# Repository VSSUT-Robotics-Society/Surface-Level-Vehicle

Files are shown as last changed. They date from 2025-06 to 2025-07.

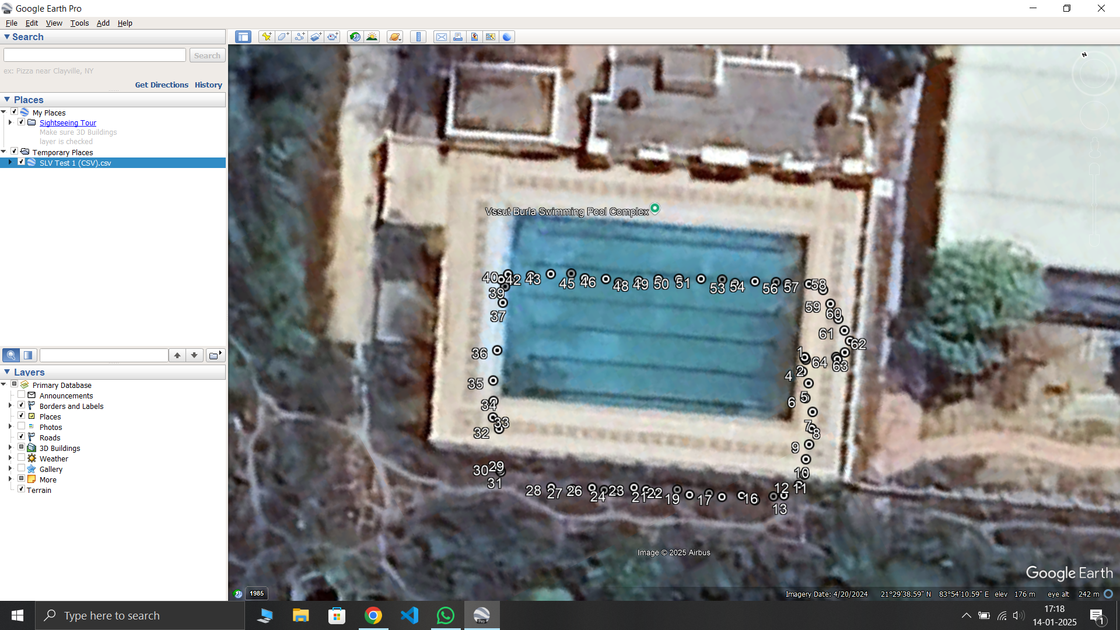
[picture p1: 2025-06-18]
Test Runs/Test_1 - Swimming Pool/SLV Test 1 (image).png

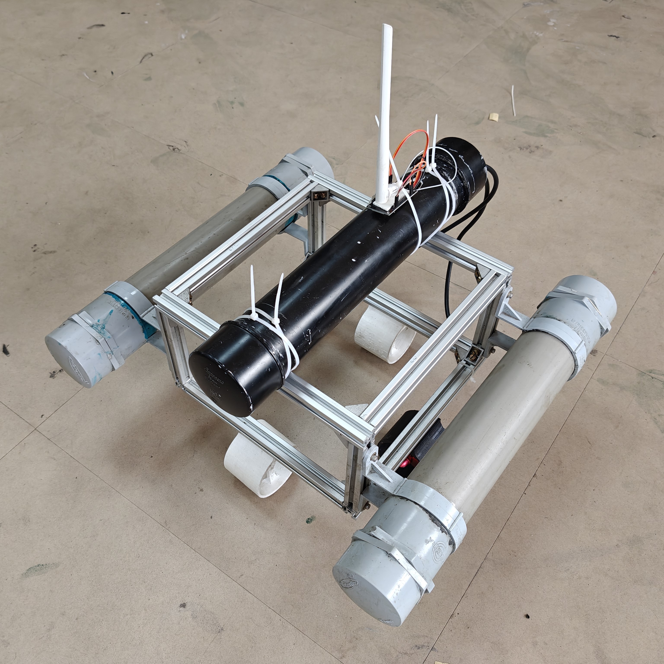
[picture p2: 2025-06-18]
Assets/1.jpg

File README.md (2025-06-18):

# Surface Level Vehicle (SLV)

An autonomous surface water robot designed for environmental monitoring, research, and rescue operations.

---

## Table of Contents
1. [Overview](#overview)
2. [Our Goals](#our-goals)
3. [What We Currently Use](#what-we-currently-use)
    - [Hardware](#hardware)
    - [Software](#software)
    - [Packages](#packages)
4. [How to Run the Project](#how-to-run-the-project)
    - [Installation](#installation)
5. [Problems Currently Being Faced](#problems-currently-being-faced)
6. [Bill of Materials Required](#bill-of-materials-required)
7. [Future Applications/Features](#future-applicationsfeatures)
8. [References](#references)

---

## Overview

The Surface Level Vehicle (SLV) is an unmanned watercraft designed for surface-level operations. It incorporates a lightweight, durable aluminum extrusion frame for structural support, enhancing stability, modularity, and ease of assembly. Powered by four BLDC motors and equipped with GPS for autonomous navigation, the SLV is built for efficient and precise aquatic missions.

---

## Our Goals

- Develop a cost-effective and modular surface vehicle.
- Enable autonomous water navigation using GPS.
- Support various environmental, research, and safety applications.
- Ensure stability, durability, and ease of customization.

---

## What We Currently Use

### Hardware

- Aluminum extrusion frame  
- 4 × High-RPM BLDC motors with waterproof propellers  
- 2 × Air-filled PVC pipes (floatation)  
- GPS module  
- Rechargeable battery pack  
- Waterproof enclosures

### Software

- Arduino IDE (for motor and GPS control)  
- Mission planning software (e.g., QGroundControl or custom path planner)

### Packages

- Easy navigation and motor control libraries (to be listed if available)

---

## How to Run the Project

### Installation

1. Connect the GPS and motor controllers to the microcontroller.
2. Upload the control code using Arduino IDE.
3. Ensure all connections are waterproof and secured.
4. Calibrate motors and GPS before deployment.

---

## Problems Currently Being Faced

- Fine-tuning GPS accuracy for precise waypoint navigation.
- Ensuring reliable waterproofing in high humidity or splash zones.
- Battery life optimization during long missions.

---

## Bill of Materials Required

| Item | Quantity | Description |
|---|---|---|
| Aluminum extrusions | xN | Main structural frame |
| BLDC Motors (Waterproof) | 4 | Propulsion |
| Propellers | 4 | Attached to motors |
| PVC Pipes (Floatation) | 2 | Buoyancy and stability |
| GPS Module | 1 | Navigation |
| Rechargeable Battery | 1 | Power source |
| Waterproof Enclosure | N | Electronics protection |

---

## Future Applications/Features

- Solar power integration using the flat frame surface  
- Mounting of advanced sensors (LIDAR, sonar, turbidity, etc.)  
- Hydrodynamic optimization of float structures  
- Modular add-ons for different missions (sample collectors, probes)

---

## References

- Internal project documentation  
- Arduino & sensor datasheets  
- Research on autonomous surface vehicles

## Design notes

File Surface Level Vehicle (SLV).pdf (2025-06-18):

# Surface Level Vehicle (SLV)

An autonomous surface water robot

Introduction:
The Surface Level Vehicle (SLV) is an unmanned watercraft designed for
surface-level | operations. | This
incorporates a lightweight, durable aluminum extrusion frame for structural support, enhancing stability, modularity, and ease of assembly. Propelled by four BLDC motors, equipped with GPS for autonomous navigation, and buoyed by air-filled PVC pipes, this SLV is designed for efficient and precise operations.

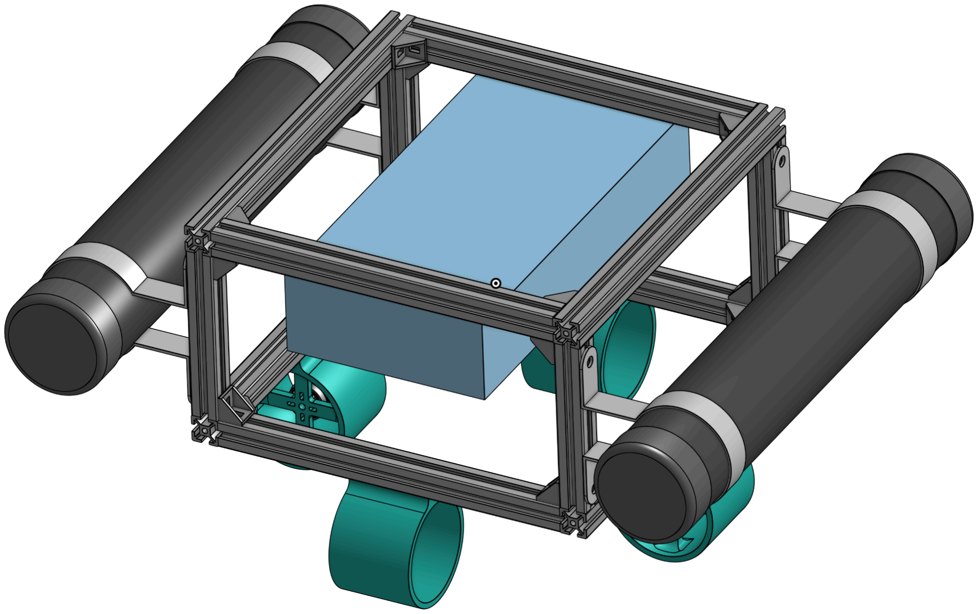
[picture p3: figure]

Isometric View

### 2. Design and Construction

### 2.1. Structural Design

- The ASV’s mainframe is constructed using aluminum extrusions, offering: Lightweight durability: Resistant to corrosion and suitable for marine environments. Modularity: Easy assembly, disassembly, and customization.
High strength-to-weight ratio: Ensures robustness while minimizing weight.
- The aluminum extrusion frame provides a rigid platform for mounting motors, electronic components, and sensors.
- Two air-filled PVC pipes are securely attached to the aluminum frame, serving as floatation devices. These pipes are placed parallel to each other to maximize stability in water.

### 2.2. Propulsion System

- Four high-RPM BLDC motors are mounted symmetrically on the aluminum frame.
- The motor mounts are designed for easy installation and maintenance.
- Waterproof propeller systems ensure efficient propulsion.

### 2.3. Navigation System

- A GPS module is integrated for precise waypoint tracking and autonomous navigation.
- The navigation system is housed in a waterproof enclosure mounted on the aluminum frame.

### 2.4. Power System

- The ASV is powered by rechargeable batteries securely mounted on the aluminum structure.
- Wiring is neatly routed through the aluminum channels for protection and aesthetics.

### 4. Applications

1. Environmental Monitoring: Collecting water quality and biodiversity data.
2. Hydrographic Surveys: Mapping underwater terrain.
3. Scientific Research: Supporting experiments and data collection in aquatic environments.
4. Search and Rescue: Locating missing objects or individuals in water bodies.

### 5. Future Scope

1. Solar Power Integration:
- Aluminum extrusions provide a stable platform for mounting solar panels.
2. Advanced Sensors:
- Easy installation of sonar, LIDAR, or water quality sensors on the frame.
3. Hydrodynamic Design:
- Exploring streamlined PVC pipe shapes for reduced drag and improved efficiency.
4. Multi-Mission Capability:
- Modular frame allows for quick reconfiguration for different missions.

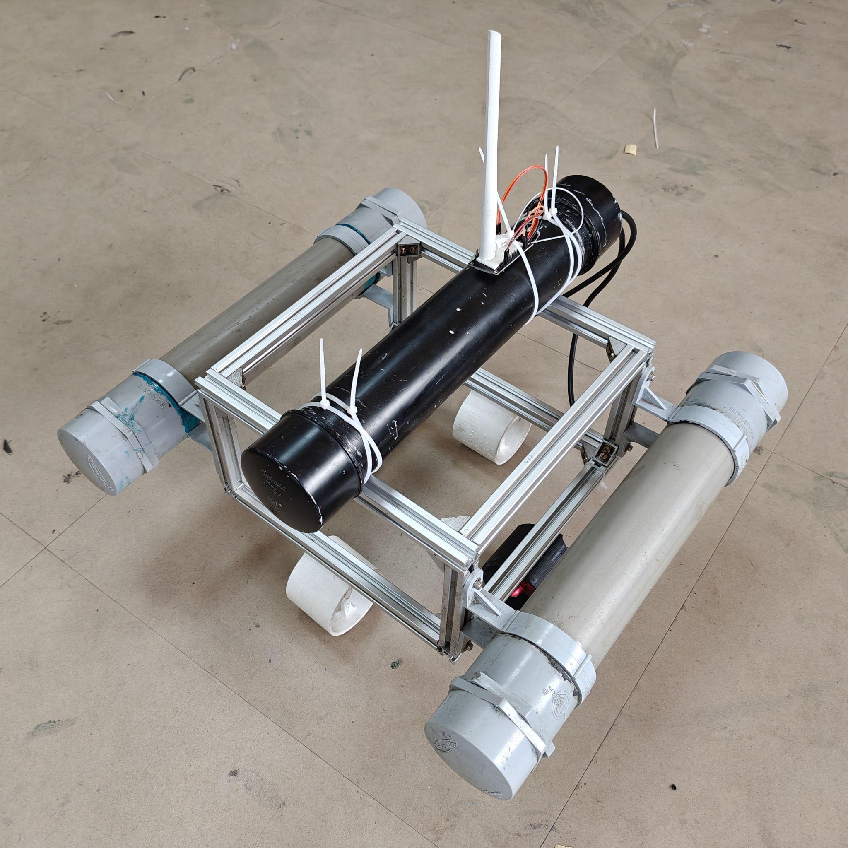
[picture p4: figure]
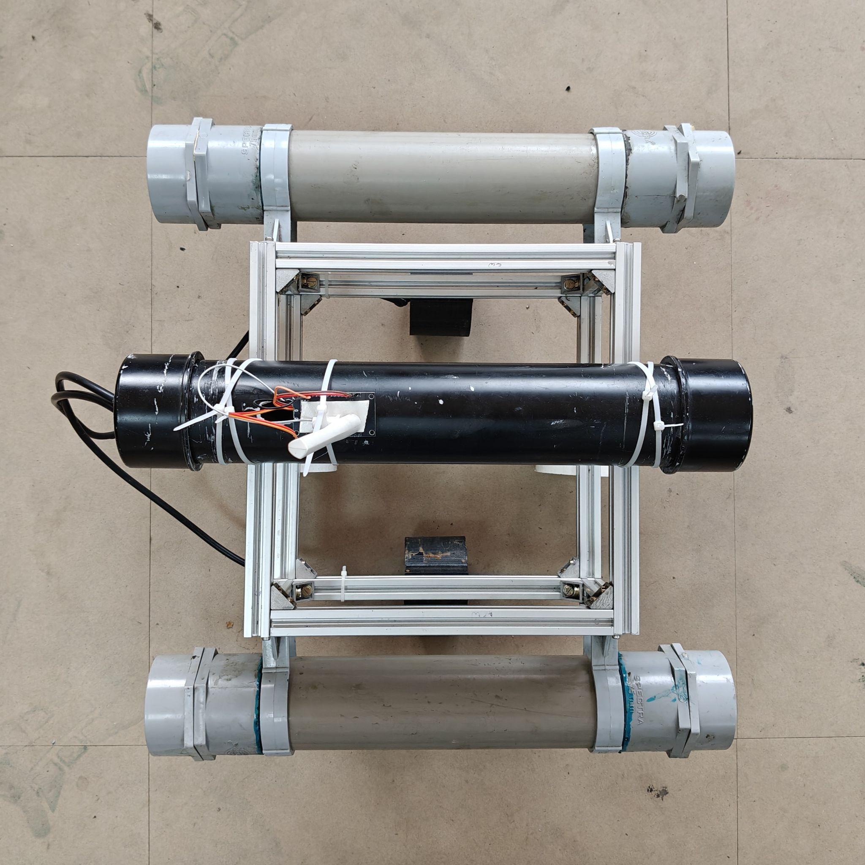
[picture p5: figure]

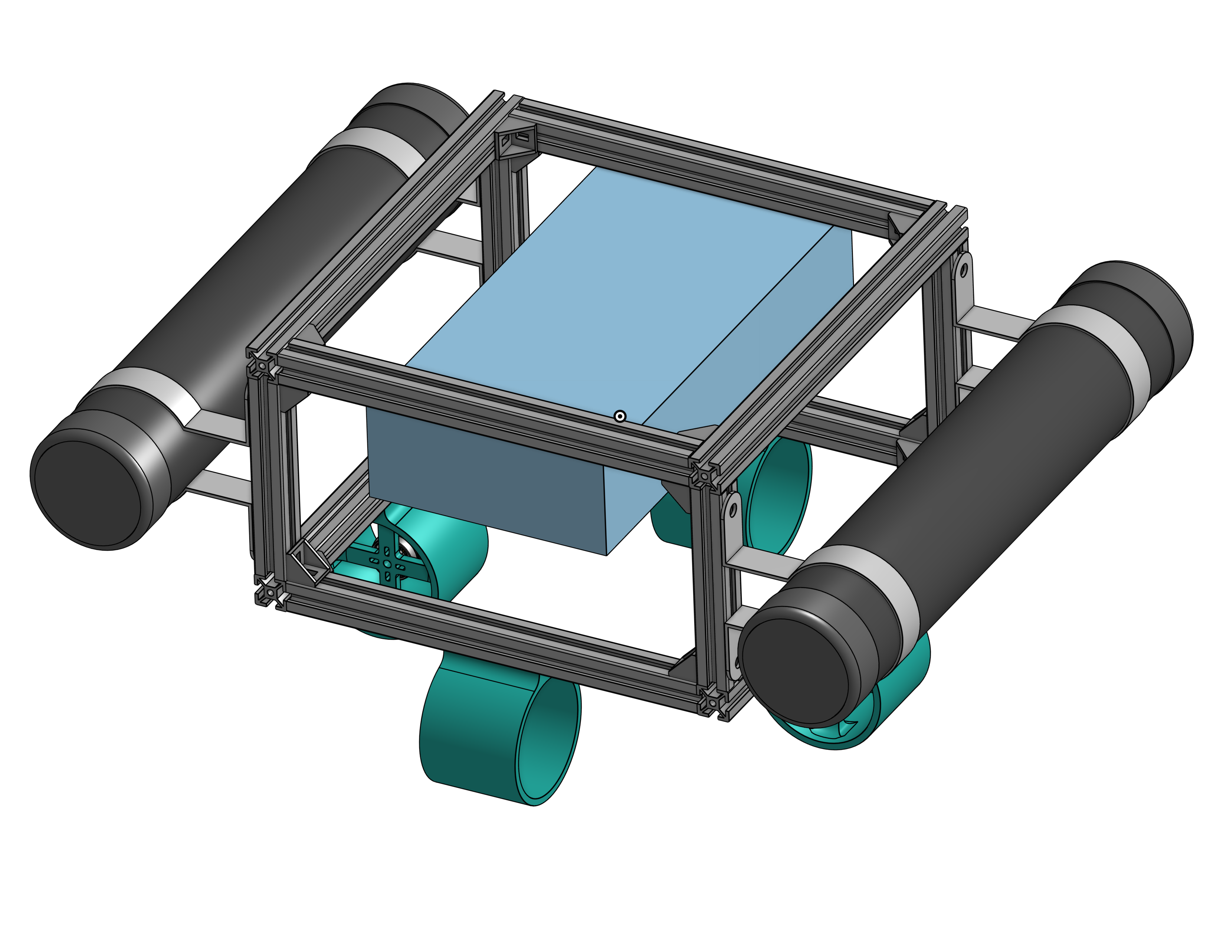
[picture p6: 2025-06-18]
CAD/isometric.png

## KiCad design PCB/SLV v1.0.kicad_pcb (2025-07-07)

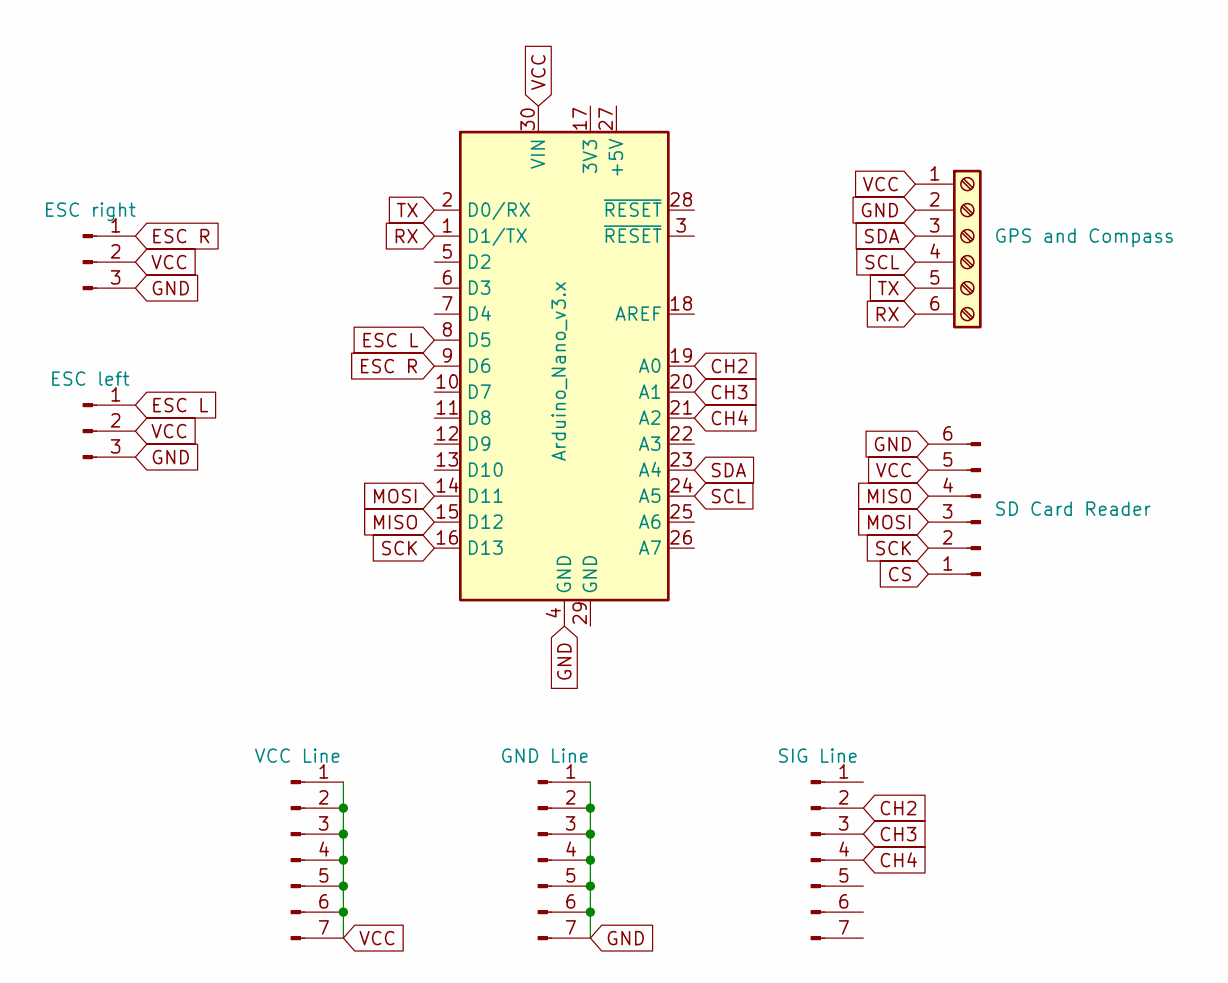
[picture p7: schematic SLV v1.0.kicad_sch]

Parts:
A1: Arduino_Nano_v3.x; Arduino_Nano
J1: GPS and Compass; TerminalBlock_bornier-6_P5.08mm
J2: SD Card Reader; PinHeader_1x06_P2.54mm_Vertical
J3: ESC left; PinHeader_1x03_P2.54mm_Vertical
J4: ESC right; PinHeader_1x03_P2.54mm_Vertical
J5: VCC Line; PinHeader_1x07_P2.54mm_Vertical
J6: GND Line; PinHeader_1x07_P2.54mm_Vertical
J7: SIG Line; PinHeader_1x07_P2.54mm_Vertical

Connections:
CH2: A1.19 (A0), J7.2
CH3: A1.20 (A1), J7.3
CH4: A1.21 (A2), J7.4
CS: J2.1
ESC L: A1.8 (D5), J3.1
ESC R: A1.9 (D6), J4.1
GND: A1.4 (GND), J1.2, J2.6, J3.3, J4.3, J6.1, J6.2, J6.3, J6.4, J6.5, J6.6, J6.7
MISO: A1.15 (D12), J2.4
MOSI: A1.14 (D11), J2.3
RX: A1.1 (D1/TX), J1.6
SCK: A1.16 (D13), J2.2
SCL: A1.24 (A5), J1.4
SDA: A1.23 (A4), J1.3
TX: A1.2 (D0/RX), J1.5
VCC: A1.30 (VIN), J1.1, J2.5, J3.2, J4.2, J5.1, J5.2, J5.3, J5.4, J5.5, J5.6, J5.7

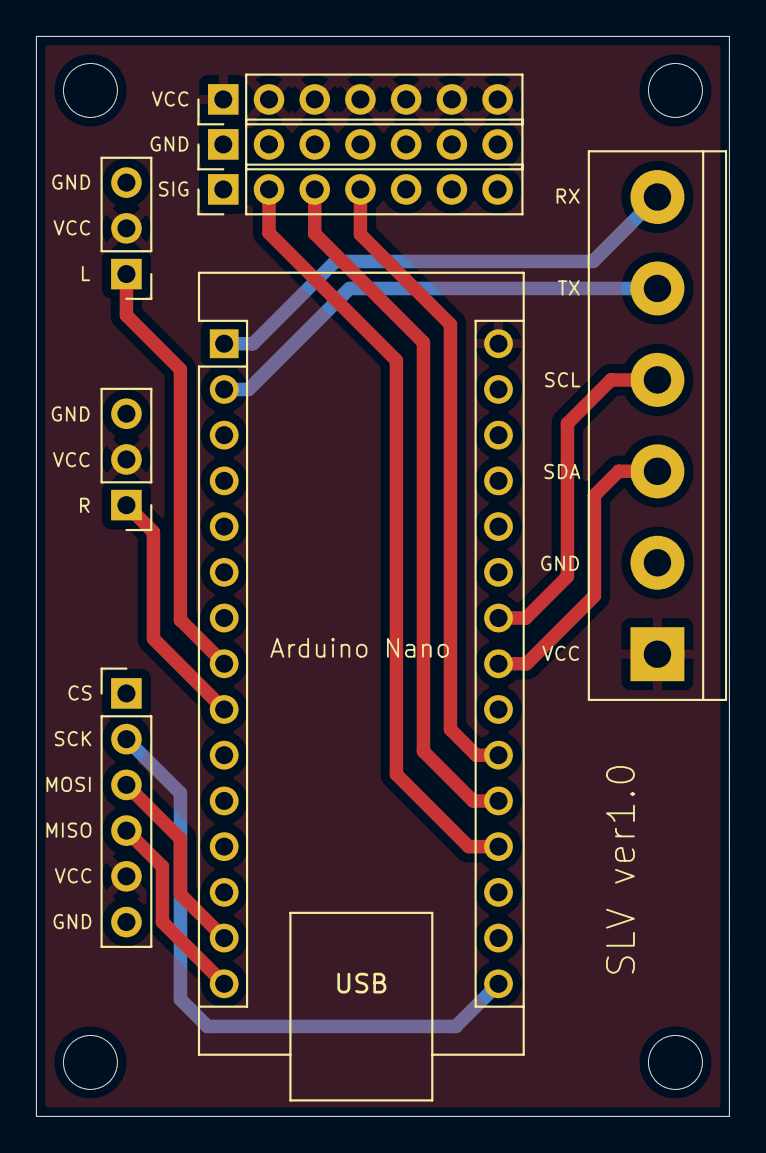
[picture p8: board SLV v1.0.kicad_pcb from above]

Board: 2 copper layers, 38.5 x 60.0 mm, 8 parts (0 on the bottom side), 14 nets.

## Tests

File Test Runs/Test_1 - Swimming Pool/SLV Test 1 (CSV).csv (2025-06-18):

SL | Latitude | Longitude
1 | 21.494125 | 83.902946
2 | 21.494125 | 83.902946
3 | 21.494123 | 83.902946
4 | 21.494116 | 83.902939
5 | 21.494106 | 83.902939
6 | 21.494097 | 83.902931
7 | 21.494085 | 83.902931
8 | 21.494074 | 83.902924
9 | 21.494064 | 83.902916
10 | 21.494055 | 83.902908
11 | 21.494045 | 83.902901
12 | 21.49404 | 83.902893
13 | 21.494038 | 83.902878
14 | 21.494041 | 83.90287
15 | 21.494045 | 83.902855
16 | 21.494053 | 83.902847
17 | 21.494059 | 83.902832
18 | 21.494066 | 83.902824
19 | 21.494072 | 83.902809
20 | 21.49408 | 83.902802
21 | 21.494085 | 83.902786
22 | 21.494091 | 83.902779
23 | 21.494097 | 83.902771
24 | 21.494101 | 83.902756
25 | 21.494106 | 83.902748
26 | 21.494112 | 83.90274
27 | 21.494118 | 83.902725
28 | 21.494127 | 83.90271
29 | 21.494156 | 83.902679
30 | 21.49416 | 83.902679
31 | 21.494158 | 83.902679
32 | 21.494186 | 83.902695
33 | 21.494196 | 83.902695
34 | 21.494207 | 83.902702
35 | 21.494221 | 83.90271
36 | 21.49424 | 83.902725
37 | 21.49427 | 83.902748
38 | 21.49428 | 83.902756
39 | 21.494286 | 83.902756
40 | 21.494287 | 83.902763
41 | 21.494282 | 83.902763
42 | 21.494278 | 83.902779
43 | 21.494272 | 83.902794
44 | 21.494265 | 83.902809
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

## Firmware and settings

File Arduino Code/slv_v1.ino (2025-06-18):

#include <Arduino.h>
#include <Wire.h>
#include <TinyGPSPlus.h>
#include <SoftwareSerial.h>
#include <math.h>

#define ch8 12
#define ch2 7
#define ch4 8
int initialFreq = 990, FinalFreq = 1980, Middlepoint = 1490;
unsigned long Switch, Movement, rotation;

#define HMC5883L_ADDR 0x1E
#define HMC5883L_REG_DATA 0x03
// Pin definitions
#define ESC1_PIN 5
#define ESC2_PIN 6

// ESC calibration timing
unsigned long calibrationTime = 2000; // Time to send max signal, in milliseconds
unsigned long minSignalTime = 2000;   // Time to send min signal, in milliseconds
unsigned long maxSignalTime = 2000;   // Time to send max signal, in milliseconds

// PWM signal range (typically between 1000 to 2000 microseconds)
int minPWM = 1000;
int maxPWM = 2000;
int neutralPWM = 1500; // Neutral signal (idle position for most ESCs)
SoftwareSerial serial_connection(2, 3);
TinyGPSPlus gps;
double lat1, lng1, lat2, lng2, magneticDeclination, trueBearing, distance;
int speed, initSpeed = 0, finalSpeed = 255;
double Target[2] = {21.4962951, 83.8977747};
double Current[2] = {0.0, 0.0};
double Kp = 2.0;

#define EARTH_RADIUS 6371.0

// Convert degrees to radians
double toRadians(double degree)
{
  return degree * (M_PI / 180.0);
}

void Calibration()
{
  Serial.println("Starting ESC calibration...");

  // Send max signal to ESCs (2000 microseconds)
  Serial.println("Sending max signal (2000 µs)...");
  analogWrite(ESC1_PIN, map(maxPWM, 0, 255, 0, 255));
  analogWrite(ESC2_PIN, map(maxPWM, 0, 255, 0, 255));
  delay(calibrationTime); // Hold max signal for calibration time

  // Send min signal to ESCs (1000 microseconds)
  Serial.println("Sending min signal (1000 µs)...");
  analogWrite(ESC1_PIN, map(minPWM, 0, 255, 0, 255));
  analogWrite(ESC2_PIN, map(minPWM, 0, 255, 0, 255));
  delay(minSignalTime); // Hold min signal for calibration time

  // Send neutral signal to ESCs (1500 microseconds)
  Serial.println("Sending neutral signal (1500 µs)..");
  analogWrite(ESC1_PIN, map(neutralPWM, 0, 255, 0, 255));
  analogWrite(ESC2_PIN, map(neutralPWM, 0, 255, 0, 255));
  delay(maxSignalTime); // Hold neutral signal for calibration time

  // End of calibration
  Serial.println("ESC calibration complete.");
}

void CurrentLocation()
{
  while (serial_connection.available())
  {
    gps.encode(serial_connection.read());
  }
  if (gps.location.isUpdated())
  {
    Current[0] = gps.location.lat();
    Current[1] = gps.location.lng();
  }
}

double haversineDistance(double lat1, double lon1, double lat2, double lon2)
{
  double dLat = toRadians(lat2 - lat1);
  double dLon = toRadians(lon2 - lon1);

  lat1 = toRadians(lat1);
  lat2 = toRadians(lat2);

  double a = sin(dLat / 2) * sin(dLat / 2) +
             cos(lat1) * cos(lat2) * sin(dLon / 2) * sin(dLon / 2);

  double c = 2 * atan2(sqrt(a), sqrt(1 - a));
  return EARTH_RADIUS * c; // Distance in km
}

double initialBearing(double lat1, double lon1, double lat2, double lon2)
{
  lat1 = toRadians(lat1);
  lat2 = toRadians(lat2);
  double dLon = toRadians(lon2 - lon1);

  double y = sin(dLon) * cos(lat2);
  double x = cos(lat1) * sin(lat2) - sin(lat1) * cos(lat2) * cos(dLon);

  double bearing = atan2(y, x);
  bearing = bearing * (180.0 / M_PI);    // Convert radians to degrees
  return fmod((bearing + 360.0), 360.0); // Normalize to 0-360 degrees
}

void initCompass()
{
  Wire.beginTransmission(HMC5883L_ADDR);
  Wire.write(0x02);
  Wire.write(0x00);
  Wire.endTransmission();
}

void readCompass(int16_t &x, int16_t &y, int16_t &z)
{
  Wire.beginTransmission(HMC5883L_ADDR);
  Wire.write(HMC5883L_REG_DATA);
  Wire.endTransmission();
  Wire.requestFrom(HMC5883L_ADDR, 6);
  if (Wire.available() == 6)
  {
    x = (Wire.read() << 8) | Wire.read();
    z = (Wire.read() << 8) | Wire.read();
    y = (Wire.read() << 8) | Wire.read();
  }
}

void turnLeft(int speed)
{
  analogWrite(ESC1_PIN, 0);
  analogWrite(ESC2_PIN, speed);
  Serial.println("Turning Left");
}
void turnRight(int speed)
{
  analogWrite(ESC1_PIN, speed);
  analogWrite(ESC2_PIN, 0);
  Serial.println("Turning Right");
}
void stop()
{
  analogWrite(ESC1_PIN, 0);
  analogWrite(ESC2_PIN, 0);
  Serial.println("Stopped, facing destination");
}

void Forward(int speed)
{
  analogWrite(ESC1_PIN, speed);
  analogWrite(ESC2_PIN, speed);
  Serial.println("Moving Forward");
}

void Angularadjust()
{
  int16_t x, y, z;
  readCompass(x, y, z);

  // Compute magnetic heading
  float magneticHeading = atan2(y, x) * 180.0 / M_PI;
  if (magneticHeading < 0)
    magneticHeading += 360;

  // Convert to true heading
  float trueHeading = magneticHeading + magneticDeclination;
  if (trueHeading > 360)
    trueHeading -= 360;
  if (trueHeading < 0)
    trueHeading += 360;

  // Calculate required rotation
  float angleDifference = trueBearing - trueHeading;
  if (angleDifference > 180)
    angleDifference -= 360;
  if (angleDifference < -180)
    angleDifference += 360;

  Serial.print("True Heading: ");
  Serial.print(trueHeading);
  Serial.print(" Angle Difference: ");
  Serial.println(angleDifference);

  // Apply P-Controller for turning speed
  int turnSpeed = Kp * abs(angleDifference);
  turnSpeed = constrain(turnSpeed, 50, 255);

  if (angleDifference > 5)
  {
    turnLeft(turnSpeed);
  }
  else if (angleDifference < -5)
  {
    turnRight(turnSpeed);
  }
  else
  {
    stop();
  }

  delay(100);
}

void LinearAdjustment()
{
  double distanceToTarget = haversineDistance(Current[0], Current[1], Target[0], Target[1]);
  double distance = distanceToTarget * 1000;
  if (distanceToTarget > 5)
  {                                                  // If more than 0.5 km away
    double error = distanceToTarget - 5;             // Error: distance from the threshold
    speed = Kp * error;                              // P controller formula
    speed = constrain(speed, initSpeed, finalSpeed); // Ensure speed remains within limits
    Forward(speed);
  }
  else
  {
    stop();
  }
}

double getApproximateDeclination(double lat, double lon)
{
  return 0.1 * lat - 0.02 * lon;
}

void Autonavigation()
{
  CurrentLocation();
  lat1 = Current[0];
  lng1 = Current[1];
  lat2 = Target[0];
  lng2 = Target[1];
  magneticDeclination = getApproximateDeclination(lat1, lng1);
  trueBearing = initialBearing(lat1, lng1, lat2, lng2);
  distance = haversineDistance(lat1, lng1, lat2, lng2);
  Angularadjust();
  delay(1000);
  LinearAdjustment();
  // Serial.println(distance,6);
  // Serial.println(magneticDeclination,6);
}

void ManualNavigation(int Movement, int rotation)
{
  if (Movement >= initialFreq - 10 && Movement <= initialFreq + 200)
  {
    Forward(150);
  }
  else if (Movement >= Middlepoint - 10 && Movement <= Middlepoint + 10)
  {
    Forward(0);
  }
  else if (Movement >= FinalFreq - 200 && Movement <= FinalFreq )
  {
    Forward(254);
  }

  if (rotation >= initialFreq  && rotation <= initialFreq + 200)
  {
    turnLeft(254);
    turnRight(0);
  }
  else if (rotation >= Middlepoint - 10 && rotation <= Middlepoint + 10)
  {
    turnLeft(0);
    turnRight(0);
  }
  else if (rotation >= FinalFreq - 200 && rotation <= FinalFreq)
  {
    turnLeft(0);
    turnRight(254);
  }
  else{
    stop();
  }
}

void setup()
{
  Serial.begin(9600);
  serial_connection.begin(9600);
  Serial.println("GPS Start, by akramslab");
  pinMode(ESC1_PIN, OUTPUT);
  pinMode(ESC2_PIN, OUTPUT);
  pinMode(ch8, INPUT);
  pinMode(ch4, INPUT);
  pinMode(ch2, INPUT);
  Calibration();
  Wire.begin();
  initCompass();
}

void loop()
{
  Switch = pulseIn(ch8, HIGH, 25000);
  Movement = pulseIn(ch2, HIGH, 25000);
  rotation = pulseIn(ch4, HIGH, 25000);
  if (Switch != 0 && Movement != 0 && rotation != 0)
  {
    if (Switch >= initialFreq - 10 && Switch <= initialFreq + 10)
    {
      ManualNavigation(Movement, rotation);
    }
    else if (Switch >= FinalFreq - 10 && Switch <= FinalFreq + 10)
    {
      Autonavigation();
    }
  }
  else
  {
    Serial.print("RC is not connected");
    stop();
  }
}

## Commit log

2025-06-18 Surface Level Vehicle
    [SLV Test 1 (CSV).csv]
2025-07-04 Restructured files hierarchy
    [SLV Test 1 (CSV).csv]
2025-07-07 First draft of PCB Design completed
    [SLV v1.0.kicad_pcb, SLV v1.0.kicad_sch]
